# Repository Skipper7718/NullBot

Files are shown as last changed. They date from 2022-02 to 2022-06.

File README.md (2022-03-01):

# NullBot Mark 1
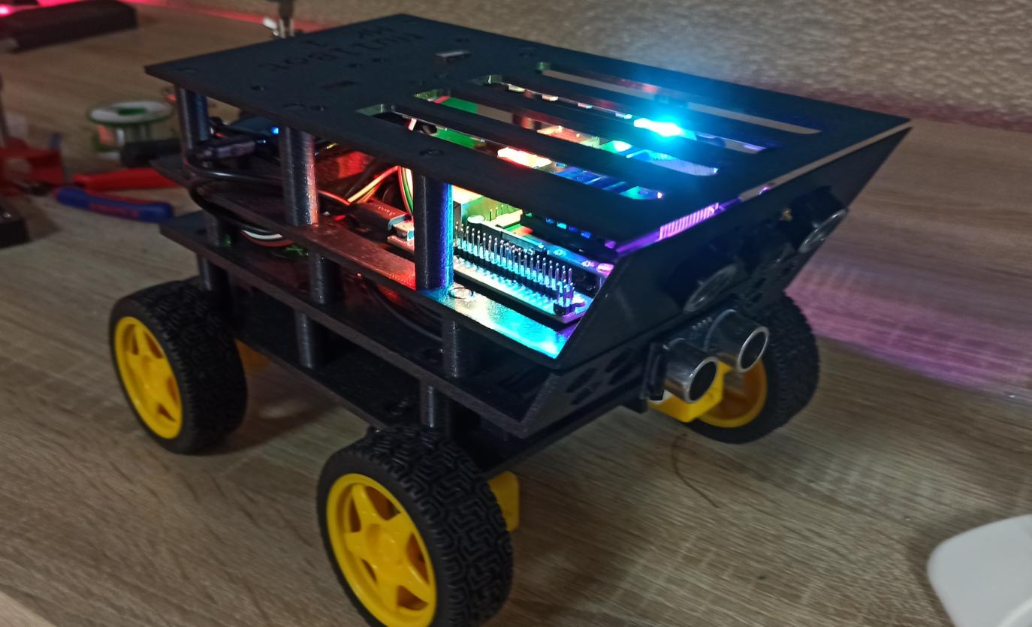
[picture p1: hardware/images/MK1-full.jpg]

Current Todo:
* Ultrasonic Sensor programming
* mainboard pcb schematic
* other modules
* documentation

# About
This is a modifiable AI robot project using a Jetson Nano at its core. It is designed to be easy to build (it just snaps together with no glue required) and easy to modify. This can be done with modules, which connect to a shared bus system and can be accessed very easily. Everything except the base is considered a module. The tires in the images also are a module. The robot features easy camera control and an AI-stack, which makes it easy to use many neural nets on the bot.

### **Features**:
* Jetson Nano as a core for stable control and AI capabilities.
* ESP-32 coprocessor to handle the module bus and other parts of the bot.
* Wifi antenna
* Infrared camera
* Big battery
* Ultrasonic distance sensor
* RGB lighting
* Everything else that can be done with modules

### **Modules**:
Modules play a special role in this project. Everything aside the main body is considered a module. Two modules can be attached to the top and one to the bottom, as well as one directly to the main board. I have remapped a USB connection for easier attachment.

Available modules include (unchecked boxes are to-do):

- [x] Drive Module (attached in pictures)
- [x] Dev Module (create custom modules)
- [ ] LiDAR module
- [ ] BME680
- [ ] LoRA module

The modules I make in this project are located in `modules.py`. An example script for controlling the wheels of an attached drive module:
```python
from nullbot import modules

# the script will panic if the module is not physically attached
bot = modules.DriveModule()

# drive forward for one second
bot.forward(1)
```
### **Camera**:
The camera in this project is a normal IR camera compatible with raspberry pi. You can register a callback function which takes a PIL image as parameter, which will then be executed as a LoopThread (watchdog). The camera can also be a target in the AI Stack.
### **AI Stack**:
The Jetson Nano contains CUDA-cores, whch can be used for accelerated neural networks. To run many models easy and with the same resources, the nullbot contains an *AI Stack*. Models / Wrapper Models that inhertit `StackNetwork` from ai.py can be put onto the AI stack. There are two types of stack, an image stack and a misc stack. The Image stack can use models that take a PIL Image as parameter, other models can be put onto another stack. With `run_stack(*args)` you can run a stack, for example as callback frunction for the camera, which returns an Image. The stack determins by itself, if it should use the image or misc stack. If activated, the bot will run the `ai_stack` function. The stack can be for example used with an avoidance network. An example code for the AI stack:
```python
from nullbot import ai, camera
from PIL import Image

class MyModel(ai.StackNetwork):
    # This is an image stack network
    image = True

    def __init__(self) -> None:
        # your neural net here
        pass

    def ai_stack(self, img:Image) -> None:
        # do some inference here
        pass

model = MyModel()
ai.add_to_stack(model)
camera.camera_with_callback(ai.run_stack)
```
### **WatchDog**:
When the bot is running, it is important, that crashing tasks dont interrupt the whole bot. For that purpose the bot has LoopThreads. Example code:
```python
from nullbot import watchdog
from time import sleep

def test():
    print("ping")
    sleep(1)

thread = watchdog.LoopThread(target=test, daemon=True, name="Example Thread")
thread.start()
```
## Hardware
The case is 3d printed (stl files in `hardware/stl`)

Needed materials:
* Jetson Nano
* Infrared Camera
* Alfa Wifi Adapter
* ESP32
* NullBot Junction PCBs
* WS2812 LEDs
* Ultrasonic sensor
* Battery Pack
* other small stuff

## Software
To set up nullbot Jetson Nano:
1. Flash the [JetPack](https://developer.nvidia.com/embedded/jetpack) image
2. Install neede python packages onto the jetson nano
3. You have to build OpenCV with Gstreamer support from source
4. copy [the nullbot package](software/JetsonCore/nullbot/) to python site-packages directory

To set up nullbot ESP32 coprocessor:
1. Install [ESP-IDF](https://docs.espressif.com/projects/esp-idf/en/latest/esp32/get-started/index.html)
2. go to [the coprocessor source](software/ESPHelper)
3. `get_idf`
4. `idf.py menuconfig`
5. go to Component config -> i2c master config
6. set sda and scl pin
7. go to Serial flasher config and set flash size
8. exit and save
9. `idf.py -p /dev/ttyUSB0 flash`

# Available Modules
## Drive Module
The drive module uses two H-bridges and a Pi Pico microcontroller as main chip. The default i²c address is `0x56`.
## Dev Module
The dev module uses an ESP32 as processor and can be used to prototype custom modules very easy. Up until now libraries are only available for ESP-IDF and Pico SDK, an Arduino Library in on the way.

## Images
---
Assembled Bot with Drive Module
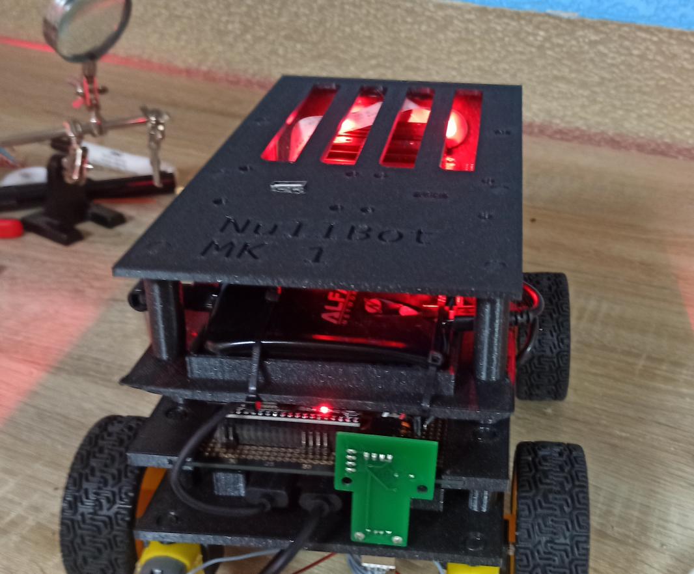
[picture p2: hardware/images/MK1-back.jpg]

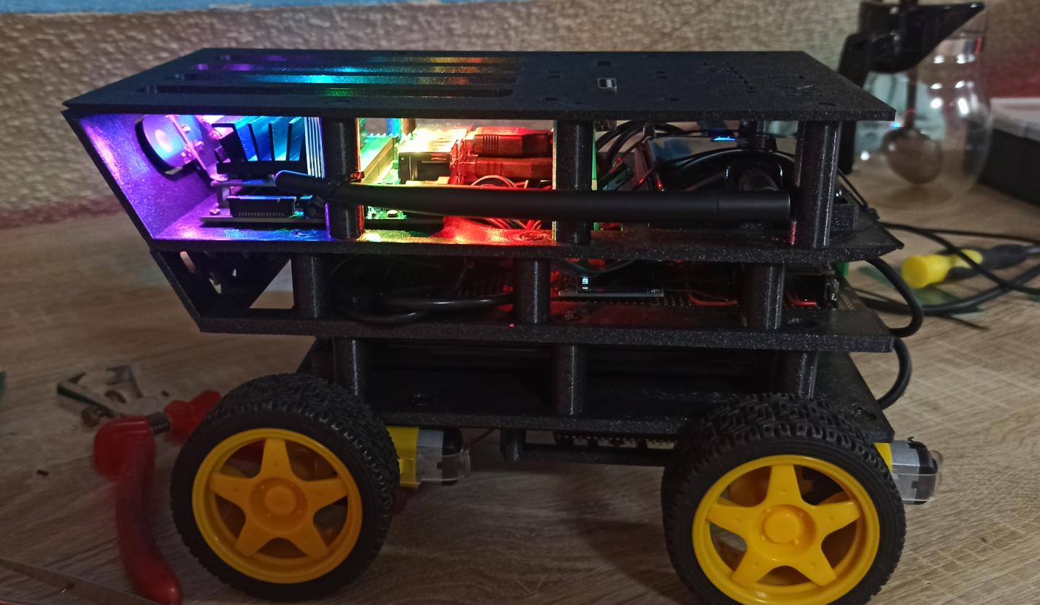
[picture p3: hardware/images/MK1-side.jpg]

Drive Module
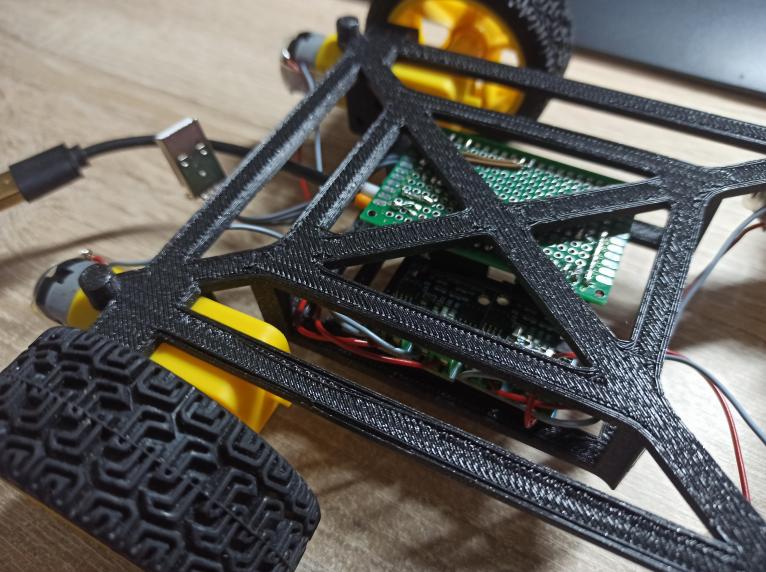
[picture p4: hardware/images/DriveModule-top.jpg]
Drive Module top

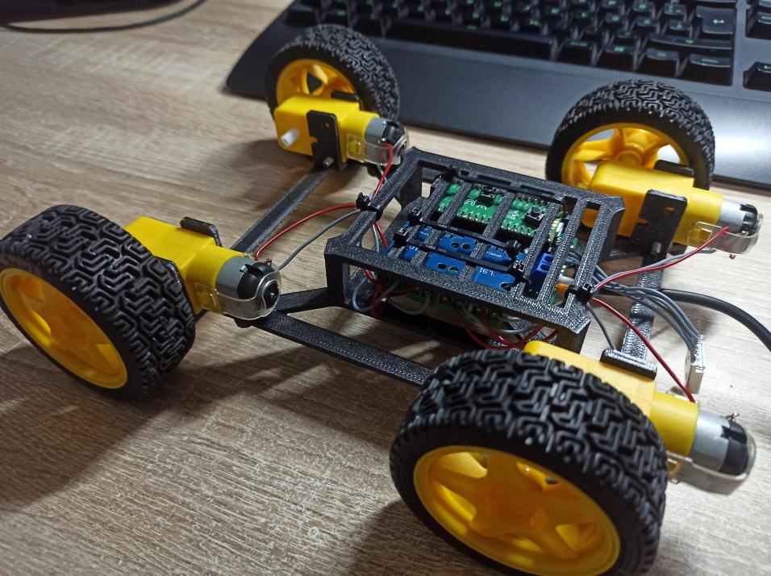
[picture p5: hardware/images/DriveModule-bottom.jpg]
Drive Module bottom

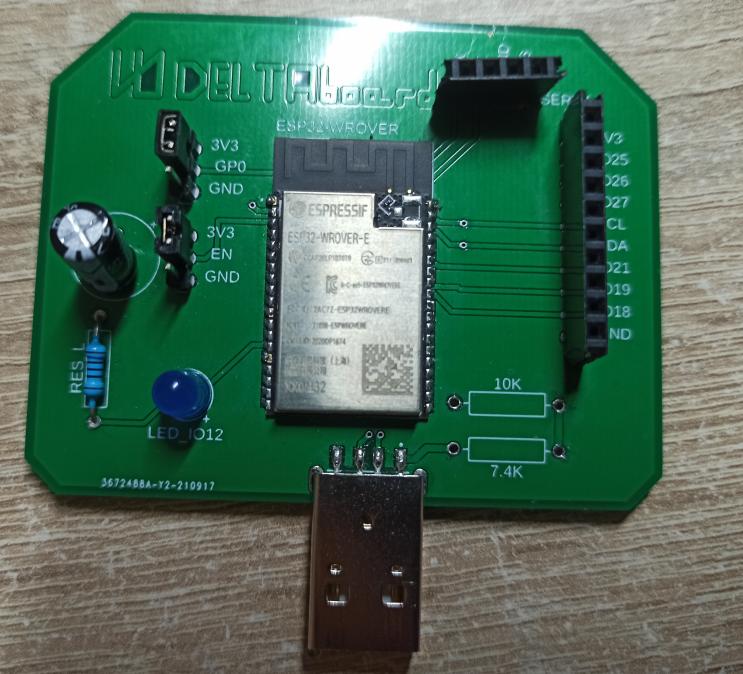
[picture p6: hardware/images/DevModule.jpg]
Dev Board

RGB lighting
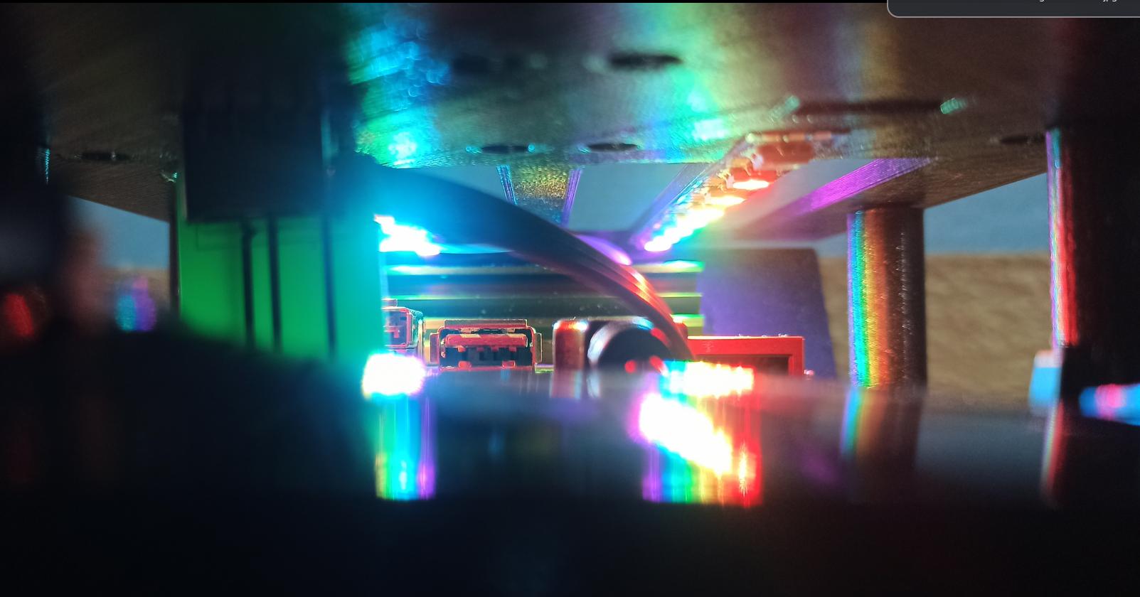
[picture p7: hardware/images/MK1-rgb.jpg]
RGB lighting

Prototyping and programming (white prototype)
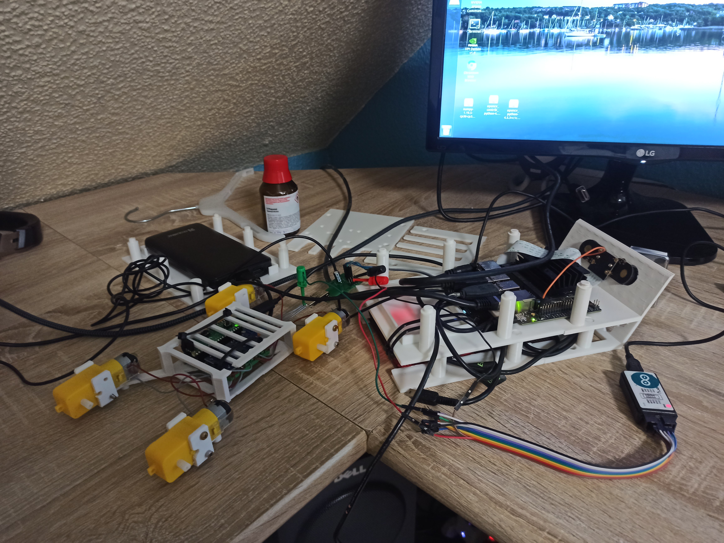
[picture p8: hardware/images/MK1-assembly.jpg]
Debugging and testing


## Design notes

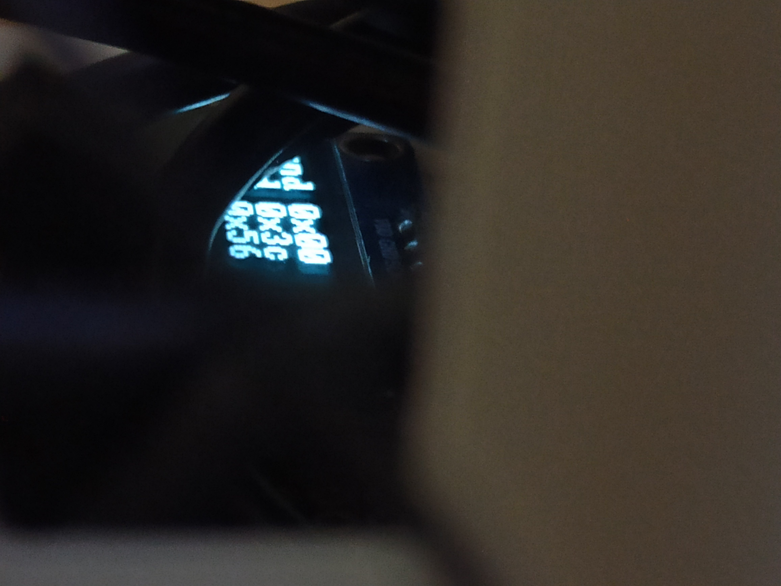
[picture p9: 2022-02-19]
hardware/images/MK1-oled.jpg

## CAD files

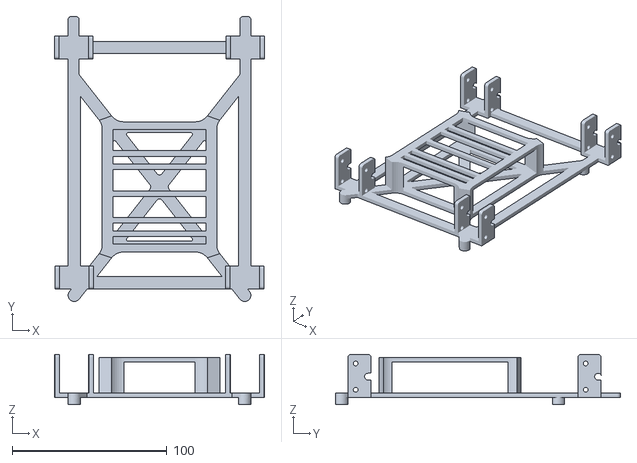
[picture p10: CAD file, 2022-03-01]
hardware/stl/drive_module/model.stl
135.9 x 184.0 x 32.5

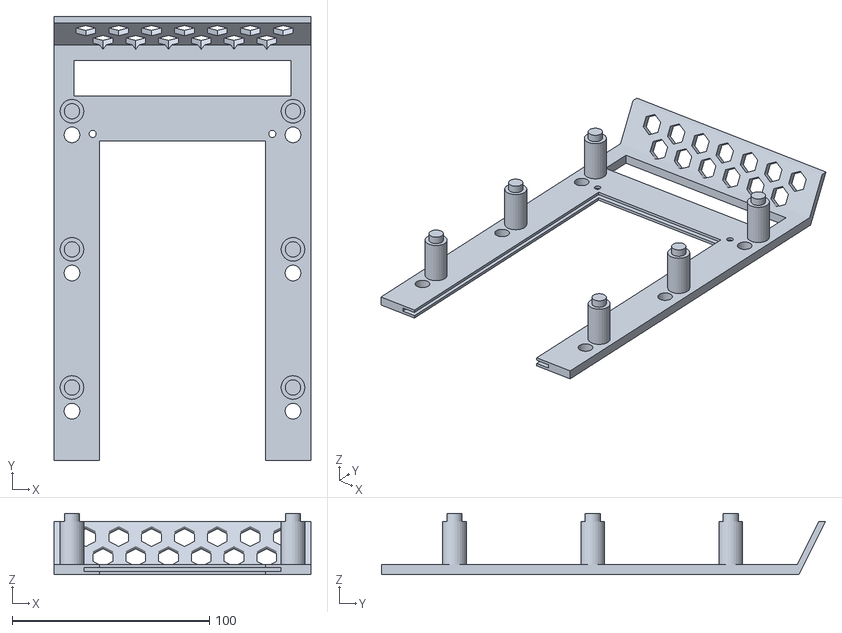
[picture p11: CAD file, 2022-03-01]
hardware/stl/main_body/pcb_layer.stl
130.0 x 225.0 x 31.0

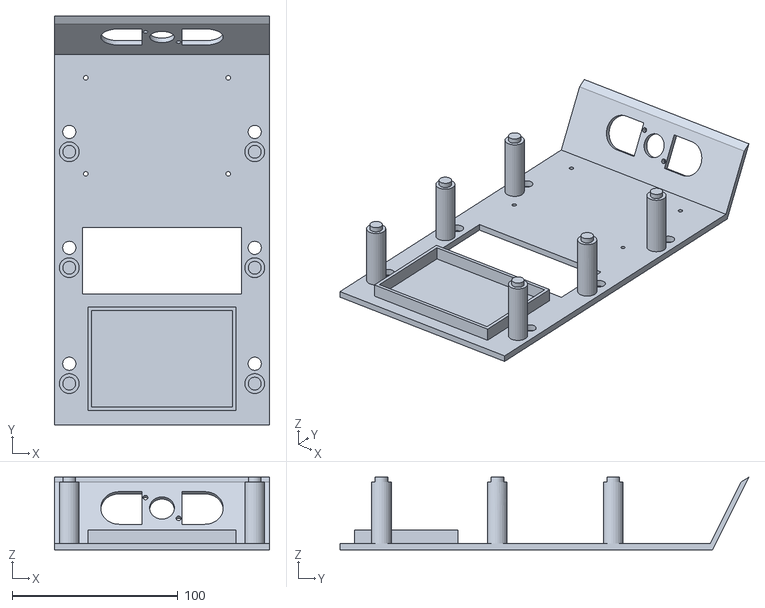
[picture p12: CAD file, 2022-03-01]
hardware/stl/main_body/core_layer.stl
130.0 x 247.0 x 44.0

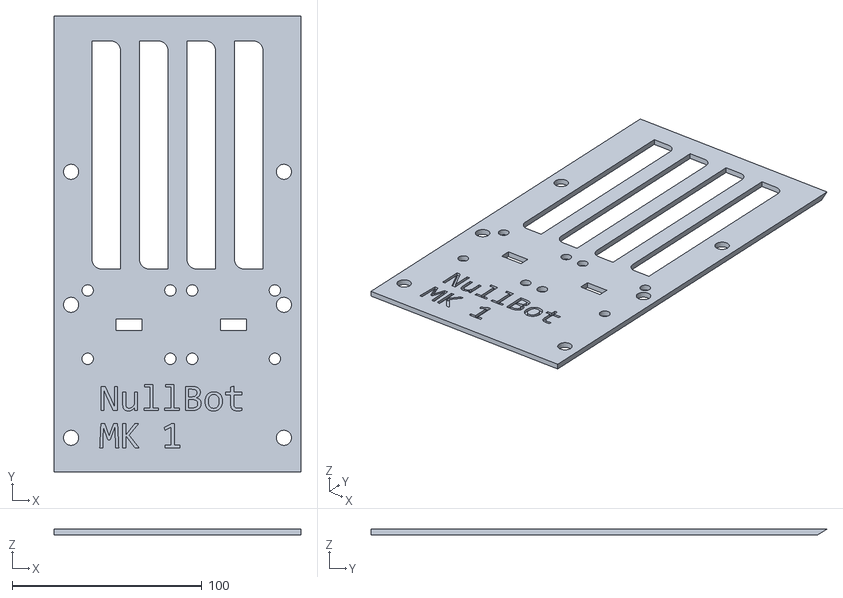
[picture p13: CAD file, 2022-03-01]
hardware/stl/main_body/top_layer.stl
130.0 x 240.0 x 3.00

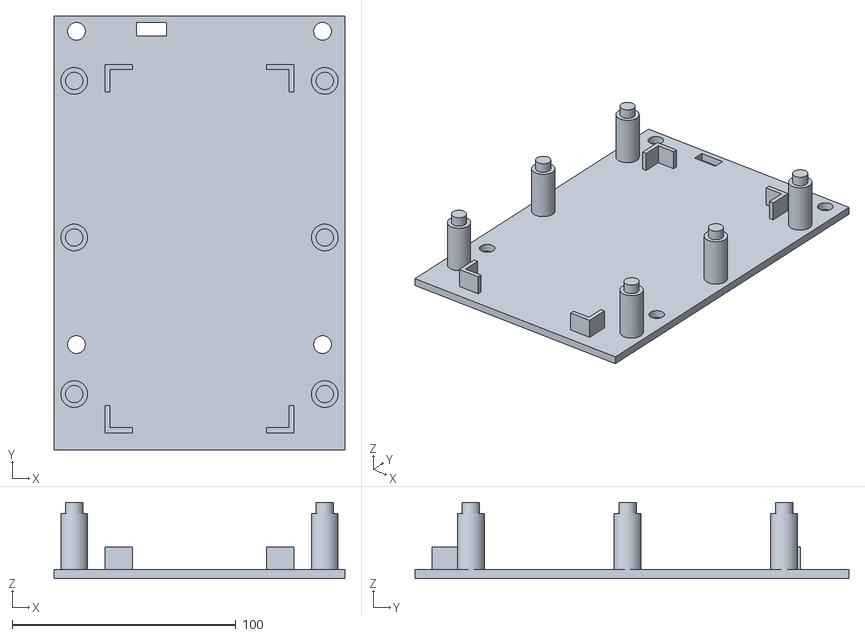
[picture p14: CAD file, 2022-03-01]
hardware/stl/main_body/battery_layer.stl
130.0 x 194.0 x 34.0

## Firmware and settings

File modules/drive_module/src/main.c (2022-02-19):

#include <stdio.h>
#include <stdint.h>
#include <stdlib.h>
#include "pico/stdlib.h"
#include "hardware/pwm.h"
#include "pico/bootrom.h"
#include "hardware/i2c.h"
#include "null_module.h"
#include "drive_module.h"

const int num_pins = 8;
static int level = 255;

long remap( long x ) {
    return map(x, 0, 255, 0, 65535);
}

void gpio_put_analog( int gpio, bool value ) {
    pwm_set_gpio_level(gpio, value ? remap(level) : 0);
}

const int pins[8] = {
    F_L_FORWARD,
    F_L_REVERSE,
    F_R_FORWARD,
    F_R_REVERSE,
    B_L_FORWARD,
    B_L_REVERSE,
    B_R_FORWARD,
    B_R_REVERSE
};

void init_drive_module() {
    //init pins
    pwm_config config = pwm_get_default_config();
    for( int i = 0; i < num_pins; i++ ) {
        gpio_set_function(pins[i], GPIO_FUNC_PWM);
        int slice_num = pwm_gpio_to_slice_num(pins[i]);
        pwm_init(slice_num, &config, true);
    }
}

void stop_all() {
    for( int i = 0; i < num_pins; i++ ) {
        gpio_put_analog(pins[i], false);
    }
}

void callback(uint8_t *payload, size_t len) {
    uint8_t command = payload[0];
    switch( command ) {
        case 0x01: // stop all motors
            stop_all();
            break;
        case 0x02: // forward
            stop_all();
            gpio_put_analog(F_L_FORWARD, true);
            gpio_put_analog(F_R_FORWARD, true);
            gpio_put_analog(B_L_FORWARD, true);
            gpio_put_analog(B_R_FORWARD, true);
            break;
        case 0x03: // right
            stop_all();
            gpio_put_analog(F_L_FORWARD, true);
            gpio_put_analog(F_R_REVERSE, true);
            gpio_put_analog(B_L_FORWARD, true);
            gpio_put_analog(B_R_REVERSE, true);
            break;
        case 0x04: // left
            stop_all();
            gpio_put_analog(F_L_REVERSE, true);
            gpio_put_analog(F_R_FORWARD, true);
            gpio_put_analog(B_L_REVERSE, true);
            gpio_put_analog(B_R_FORWARD, true);
            break;
        case 0x05: // backward
            stop_all();
            gpio_put_analog(F_L_REVERSE, true);
            gpio_put_analog(F_R_REVERSE, true);
            gpio_put_analog(B_L_REVERSE, true);
            gpio_put_analog(B_R_REVERSE, true);
            break;
        case 0x06: // simple right
            stop_all();
            gpio_put_analog(F_L_FORWARD, true);
            gpio_put_analog(B_L_FORWARD, true);
            break;
        case 0x07: // simple left
            stop_all();
            gpio_put_analog(F_R_FORWARD, true);
            gpio_put_analog(B_R_FORWARD, true);
            break;
        case 0x08: // set level
            if( len < 2 ) break;
            level = payload[1];
            break;
    }
}

int main() {
    init_i2c(26, 27, 0x56);
    sleep_ms(1000);
    init_drive_module();

    // self test
    // for( uint8_t payload = 0x07; payload > 0; payload-- ) {
    //     callback(&payload, 1);
    //     sleep_ms(1000);
    // }
    // uint8_t settings[2] = {0x08, 0xc0};
    // callback(settings, sizeof(settings));
    // for( uint8_t payload = 0x07; payload > 0; payload-- ) {
    //     callback(&payload, 1);
    //     sleep_ms(1000);
    // }

    // module loop
    start_with_callback(callback);
    for( ;; ) { tight_loop_contents(); }


    return 0;
}

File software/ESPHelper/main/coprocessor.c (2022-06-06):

#include <stdio.h>
#include <stdlib.h>
#include <stdbool.h>
#include <string.h>
#include <stdint.h>
#include "freertos/FreeRTOS.h"
#include "freertos/task.h"
#include "driver/i2c.h"
#include "driver/rmt.h"
#include "esp_err.h"
#include "esp_system.h"
#include "simple_i2c.h"
#include "esp_log.h"
#include "sh1106.h"
#include "coprocessor.h"
#include "led_strip.h"
#include "ultrasonic.h"

int num_found_addresses = 0;
uint8_t found_addresses[128];
led_strip_t *strip;
ultrasonic_sensor_t distance =  {
    .echo_pin = 26,
    .trigger_pin = 25
};

void app_main(void)
{
    //INITIALIZE COMPONENTS
    init_i2c_master();
    sh1106_init();
    ultrasonic_init(&distance);
    // ULTRASONIC TEST
    // for( ;; ) {
    //     char TAG[] = "DISTANCE";
    //     uint32_t i = 0;
    //     ultrasonic_measure_cm( &distance, 0xfd, &i );
    //     ESP_LOGI(TAG, "RESULT: %d", i);
    // }

    rmt_config_t config = RMT_DEFAULT_CONFIG_TX(RMT_TX_GPIO, RMT_TX_CHANNEL);
    // set counter clock to 40MHz
    config.clk_div = 2;

    ESP_ERROR_CHECK(rmt_config(&config));
    ESP_ERROR_CHECK(rmt_driver_install(config.channel, 0, 0));

    // install ws2812 driver
    led_strip_config_t strip_config = LED_STRIP_DEFAULT_CONFIG(LED_LEN, (led_strip_dev_t)config.channel);
    strip = led_strip_new_rmt_ws2812(&strip_config);
    if (!strip) {
        ESP_LOGE("ERROR", "install WS2812 driver failed");
    }

    // Light on
    ESP_ERROR_CHECK(fill_led(255, 0, 255));

    //SCAN FOR ADDRESSES
    print_display("\nFULL BUS SCAN");
    vTaskDelay(500 / portTICK_PERIOD_MS);
    print_display("\nFULL BUS SCAN\nrunning...");

    num_found_addresses = i2c_scan_bus(found_addresses, sizeof(found_addresses));

    print_display("\nFULL BUS SCAN\nrunning...\nDONE!");
    vTaskDelay(500 / portTICK_PERIOD_MS);
    sh1106_display_clear(NULL);
    char text[32];
    char output[128];
    memset(output, 0, sizeof(output));
    if( num_found_addresses ) {
        for( int i = 0; i < num_found_addresses; i++ ) {
            sprintf(text, "Found 0x%02x\n", found_addresses[i]);
            strcat(output, text);
        }
        print_display(output);
    } else {
        print_display("\nERROR\nNO DEVICES FOUND");
    }
    ESP_ERROR_CHECK(fill_led(140, 140, 140));

    char input[100];

    //main loop for interpreting signals
    for( ;; ) {
        int signal_length = serial_read_command(input, sizeof(input));
        interpret_signal(input, signal_length);
    }
}

void interpret_signal(char *input, int signal_length) {
    uint8_t payload[100]; //MAX TRANSFER SIZE 100 bytes
    uint8_t address;
    char text[100];
    memset(payload, 0, sizeof(payload));

    switch( input[0] ) {
        case i_read_scan:
            sprintf(text, "ECHO %d ADDRESSES\nADDRESS 0: 0x%02x | %d",num_found_addresses, found_addresses[0], found_addresses[0]);
            print_display(text);
            putchar((unsigned char) num_found_addresses);
            for(int i = 0; i < num_found_addresses; i++) {
                putchar((unsigned char) found_addresses[i]);
            }
            putchar(i_stop);
            break;
        
        case i_led_set: // The value has to be modified because 0x00 and 0xff do not get appended to 
            if( signal_length  < 5 ) break;
            sprintf(text, "LED: %d", input[1]);
            print_display(text);
            ESP_ERROR_CHECK(print_led(input[1] - 1, input[2] - 1, input[3] - 1, input[4] - 1));
            break;
        
        case i_led_fill:
            if( signal_length < 4 ) break;
            ESP_ERROR_CHECK(fill_led(input[1] - 1, input[2] - 1, input[3] - 1));
            break;

        case i_write_address:
            address = input[1];
            for( int i = 2; i < signal_length; i++ ) {
                payload[i-2] = (uint8_t) input[i];
            }
            i2c_write_bytes(address, payload, (signal_length - 2), CONFIG_I2C_PORT);
            break;
        
        case i_read_address:
            address = input[1];
            uint8_t byte = 0;
            size_t num_bytes = input[2];
            i2c_read_bytes(address, payload, num_bytes, CONFIG_I2C_PORT);
            for( int i = 0; i < num_bytes; i++ ) {
                byte = payload[i];
                if( byte != 0 || byte != 0xff ) {
                    putchar(byte);
                }
            }
            putchar(i_stop);
            break;
        
        case i_read_distance:
	    // TODO implement timeout cheker for read and assert error is failed.
	    // Now the robot blocks any kind of communication
            {
            uint32_t measurement = 0;
            ultrasonic_measure_cm( &distance, 240, &measurement );
            if( measurement <= 0xfd && measurement > 0 ) {
                putchar( (uint8_t)measurement );
                putchar( i_stop );
            }
            break;
            }

        case i_display_error:
            print_display("\n----- !!!! -----\n\nERROR\n\n----- !!!! -----");
            break;
        
        case i_display_thread_failure:
            print_display("\n----- !!!! -----\n\nTHREAD FAILED\n\n----- !!!! -----");
            break;

        case i_display_all_running:
            print_display("\n----- !!!! -----\n\nALL RUNNING\n\n----- !!!! -----");
            break;
        default:
            print_display("\n----- !!!! -----\n\nunrecognized\n\n----- !!!! -----");
            break;
    }
}

int serial_read_command(char *buffer, int buffer_len) {
    memset(buffer, 0, buffer_len);
    char c = 0;
    int i = 0;

    while( c != i_stop && i < buffer_len-1 ) {
        if( (c = getchar()) != 0xff ) {
            buffer[strlen(buffer)] = c;
            i++;
        }
        vTaskDelay(50 / portTICK_PERIOD_MS);
    }
    return i;

}

void print_display(const char *message) {
    sh1106_display_clear(NULL);
    sh1106_display_text(message);
}


esp_err_t print_led(uint32_t led_num, uint32_t r, uint32_t g, uint32_t b) {
    ESP_ERROR_CHECK(strip->set_pixel(strip, led_num, r, g, b));
    return strip->refresh(strip, 100);

}

esp_err_t fill_led(uint32_t r, uint32_t g, uint32_t b) {
    for( int i = 0; i < LED_LEN; i++ ) {
        ESP_ERROR_CHECK(strip->set_pixel(strip, i, r, g, b));
    }
    return strip->refresh(strip, 100);
}

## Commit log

2022-01-31 rework and drive module done
    [ai.py, camera.py, main.c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]
2022-02-20 added led feature
2022-02-20 locked leds in range
2022-02-21 ugly led fix
2022-03-01 add stl files
    [battery_layer.stl, core_layer.stl, model.stl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]
2022-03-20 added coprocessor ultrasonic
2022-03-20 added ultrasonic py
2022-06-03 camera can be stopped now
